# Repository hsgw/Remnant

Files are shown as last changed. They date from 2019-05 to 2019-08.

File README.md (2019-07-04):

# Remnant
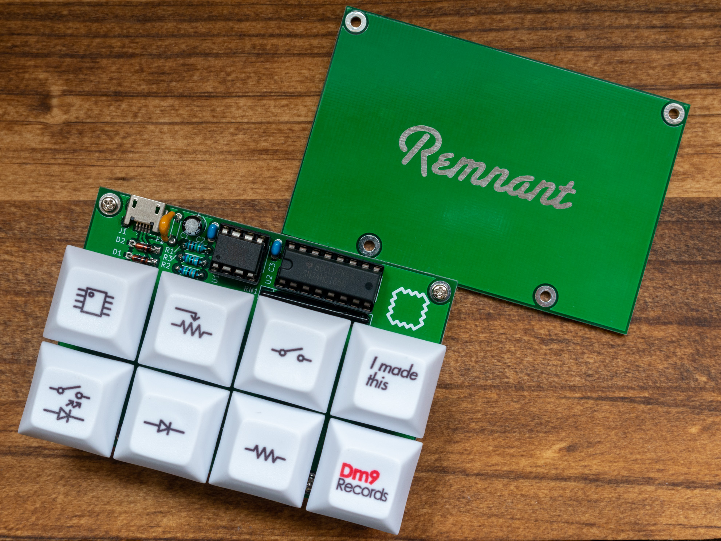
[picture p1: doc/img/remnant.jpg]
Remnant

4x2 macro keyboard with attiny85 based digispark.

# Document
- [開発環境のインストール](doc/install_env_jp.md)
- [ビルドガイド（日本語）](doc/buildguide_jp.md)

# Needs
- Arduino IDE and Digispark
https://digistump.com/wiki/digispark/tutorials/connecting

- DigisparkKeyboardExtend library 
https://github.com/hsgw/DigisparkKeyboardExtend

# License
Digispark is licensed under CC BY-SA 3.0    http://creativecommons.org/licenses/by-sa/3.0/   
(c) Digistump   

Remnant is licensed under CC BY-SA 3.0    http://creativecommons.org/licenses/by-sa/3.0/   
(c) 2019, Takuya Urakawa, dm9records.com

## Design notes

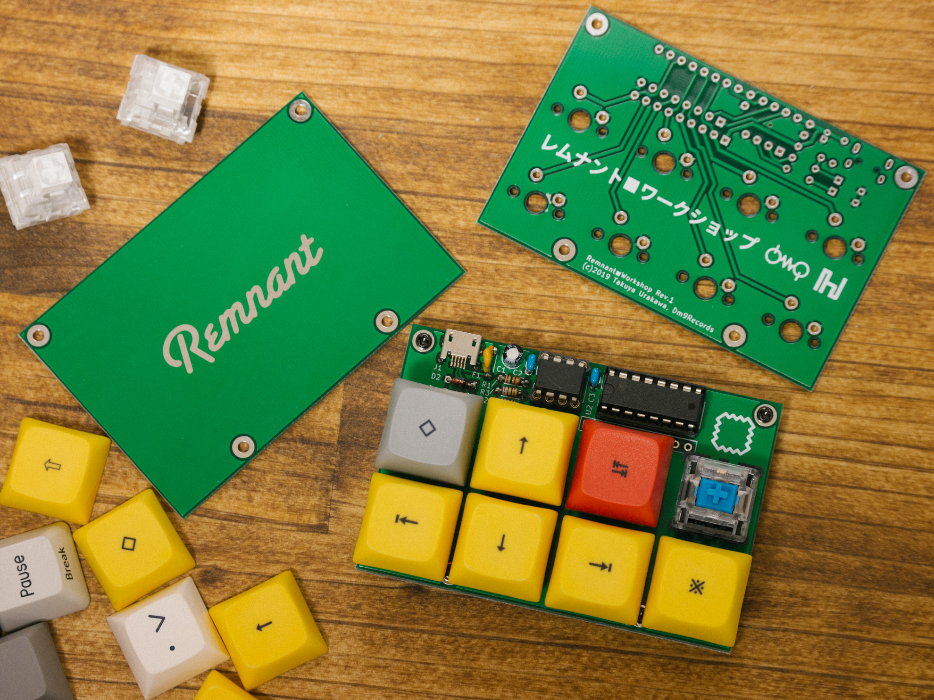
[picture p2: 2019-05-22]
remnant.jpg

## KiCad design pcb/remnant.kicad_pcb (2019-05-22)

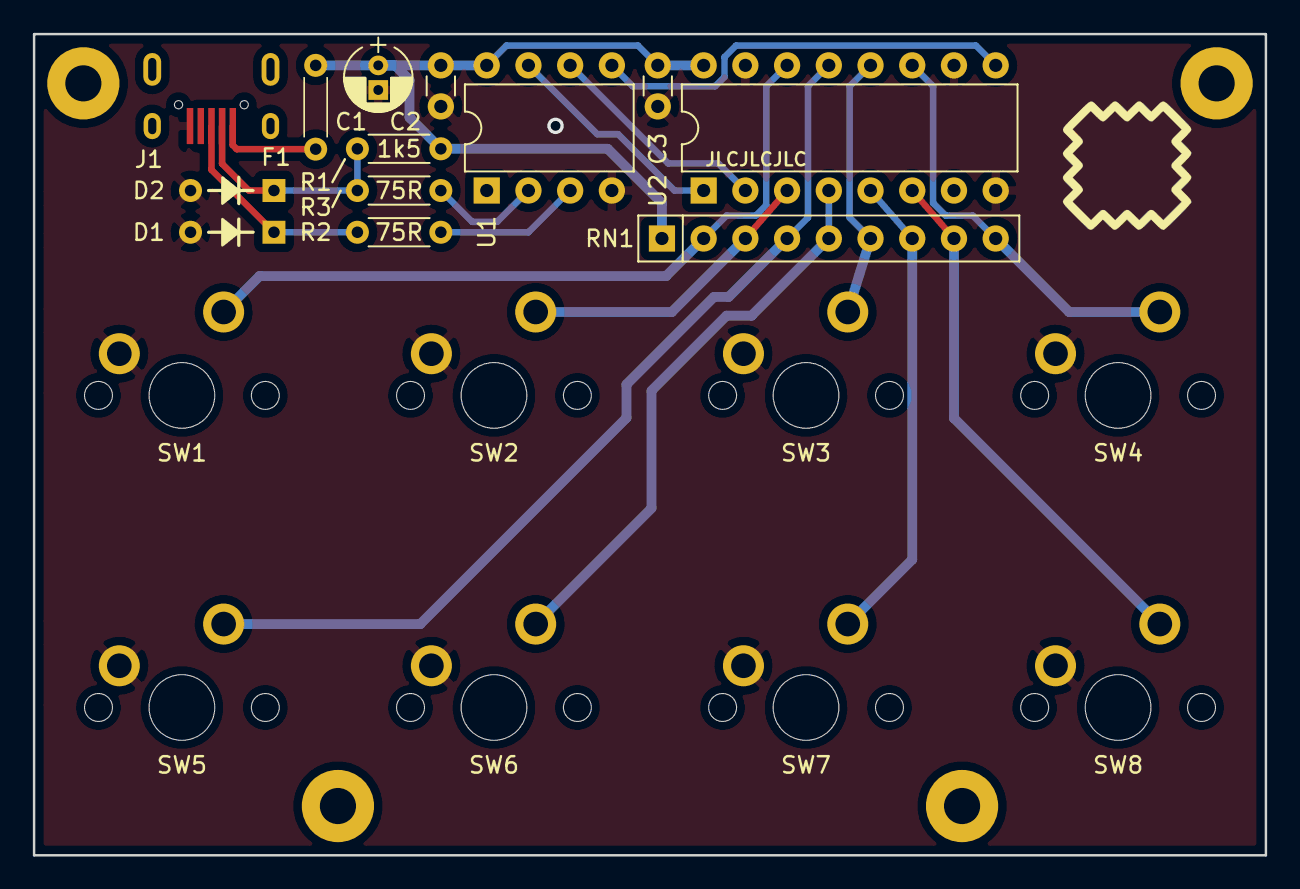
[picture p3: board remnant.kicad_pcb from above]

Board: 2 copper layers, 75.0 x 50.0 mm, 25 parts (0 on the bottom side), 18 nets.

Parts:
C1: 10u; CP_Radial_D4.0mm_P1.50mm
C2, C3: 100n; C_Disc_D3.0mm_W1.6mm_P2.50mm
D1, D2: 3.6V; D_DO-35_SOD27_P5.08mm_Horizontal
F1: 100mA; polyfuse_5.1mm
H1, H2, H3, H4: MountingHole; MountingHole_2.2mm_M2_Pad
J1: USB_OTG; USB-microB-LCSC-U-F-M5DD-W-2
R1: 1k5; R_Axial_DIN0204_L3.6mm_D1.6mm_P5.08mm_Horizontal
R2, R3: 75R; R_Axial_DIN0204_L3.6mm_D1.6mm_P5.08mm_Horizontal
RN1: R_Network08; R_Array_SIP9
SW1, SW2, SW3, SW4, SW5, SW6, SW7, SW8: MX; SW_Cherry_MX1A_1.00u_PCB
U1: ATTINY85-20PU; DIP-8_W7.62mm
U2: 74LS165; DIP-16_W7.62mm

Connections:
+5V: C1.1, C2.1, C3.1, F1.1, R1.2, RN1.1, U1.8, U2.16
/SW1: RN1.2, SW1.2, U2.14
/SW2: RN1.3, SW2.2, U2.3
/SW3: RN1.6, SW3.2, U2.12
/SW4: RN1.9, SW4.2, U2.11
/SW5: RN1.4, SW5.2, U2.13
/SW6: RN1.5, SW6.2, U2.4
/SW7: RN1.7, SW7.2, U2.5
/SW8: RN1.8, SW8.2, U2.6
/USB_D+: R2.1, U1.3
/USB_D-: R3.1, U1.2
GND: C1.2, C2.2, C3.2, D1.2, D2.2, J1.5, SW1.1, SW2.1, SW3.1, SW4.1, SW5.1, SW6.1, SW7.1, SW8.1, U1.4, U2.8, U2.10, U2.15
unnamed: D1.1, J1.3, R2.2
unnamed: D2.1, J1.2, R1.1, R3.2
unnamed: F1.2, J1.1
unnamed: U1.5, U2.9
unnamed: U1.6, U2.2
unnamed: U1.7, U2.1

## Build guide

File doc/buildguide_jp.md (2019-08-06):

# Remnant ビルドガイド

## Maker Faire Tokyo 2019にてご購入頂いた方へ
ATTINY85のbootloaderを書き忘れている物がいくつか混じっていたようです。   
誠に申し訳ありません。書き込み済みのものをお送りいたしますのでinfo@5z6p.comへご連絡頂けますでしょうか？
お手数をおかけしますが、よろしくお願いします。

- AVRへの書き込み環境のある方
以下のブートローダを書き込み、fuseを書き換えて下さい。
https://github.com/micronucleus/micronucleus

上記リポジトリをcloneしたあと、
```
cd firmwere
make CONFIG=t85_default
make CONFIG=t85_default flash
make CONFIG=t85_default fuse
```

## パーツリスト
組み立てる前にかならずパーツが全て揃っているか確認してください。

### 付属しているもの
| No | 数量 | 説明 |
|---|---|---|
| C1 | 1 | 電解コンデンサ 4.7uF |
| C2, C3 | 2 | 積層セラミックコンデンサ 0.1uF |
| D1, D2 | 2 | ショットキーダイオード 3.6V |
| F1 | 1 | ポリフューズ |
| J1 | 1 | USB microBコネクタ |
| R1 | 1 | 抵抗 1.5kΩ 茶緑黒茶茶 |
| R2, R3 | 2 | 抵抗 75Ω 紫緑黒金茶 |
| RN1 | 1 | 抵抗アレイ 10kΩx8 |
| U1 | 1 | マイコン attiny85 |
| U2 | 1 | ロジックIC 74HC165 |
| IC socket | 1 | ICソケット 16ピン |
| IC socket | 1 | ICソケット 8ピン |
| SW1-8 | 8 | MX互換スイッチ |
| キーキャップ | 8 | |
| PCB | 2 | main&bottom |
| ねじ類 | | 1セット |

### 別途必要なもの
- USB microBケーブル

## 組立

### ダイオードのはんだづけ
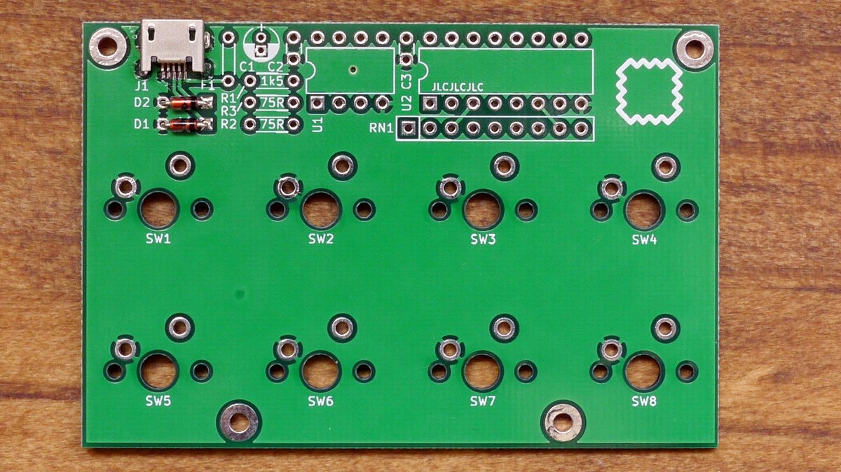
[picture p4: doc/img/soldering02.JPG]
diode


ダイオードには**実装する向き**があります。   
**部品の帯**と**基板シルクの線がある方**を合わせてください。

### 抵抗のはんだづけ
抵抗は2種類あります。間違えないように注意。

#### R1 (1.5kΩ)
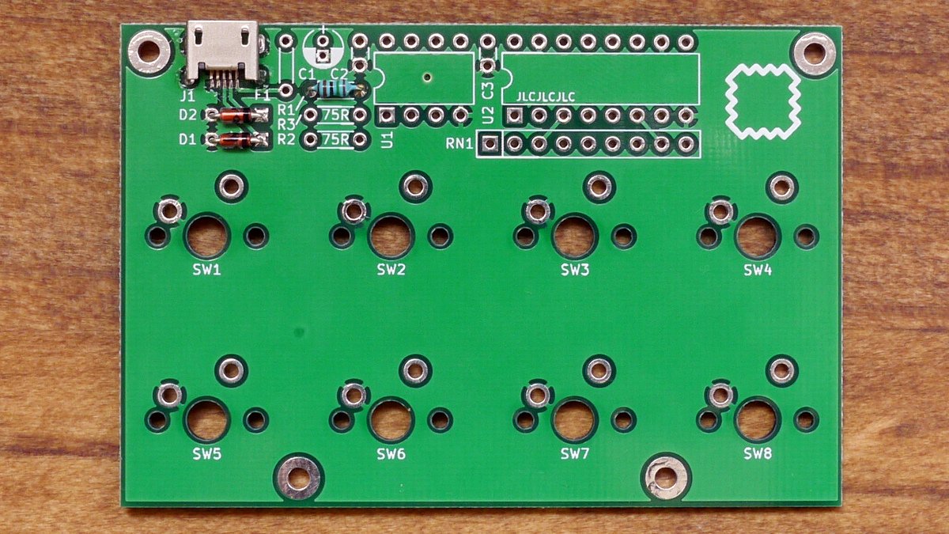
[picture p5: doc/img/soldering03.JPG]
1.5k


#### R2-3 (75Ω)
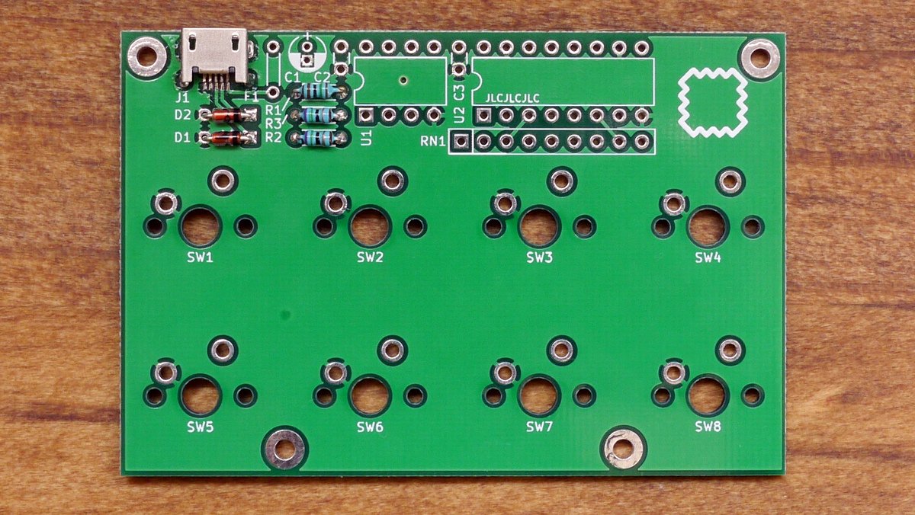
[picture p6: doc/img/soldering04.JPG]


### 積層セラミックコンデンサのはんだづけ
C2とC3をはんだづけします。
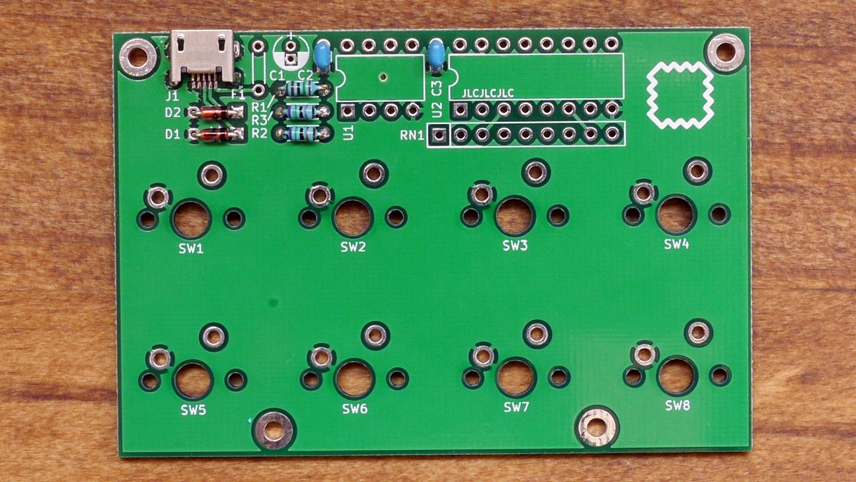
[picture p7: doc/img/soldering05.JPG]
0.1uF


### 抵抗アレイとICソケットのはんだづけ
抵抗アレイには**実装する向き**があります。   
**部品上のマーキング**と**基板シルクで囲まれたピン**を合わせてください。
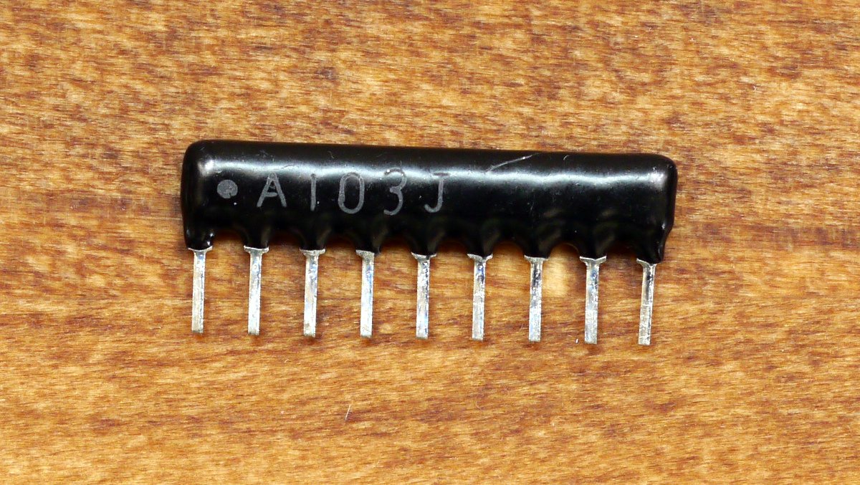
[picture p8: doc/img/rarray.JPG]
rarray


ICソケットには**実装する向き**があります。   
**部品の切りかけ**と**基板シルクの切りかけ**を合わせてください。

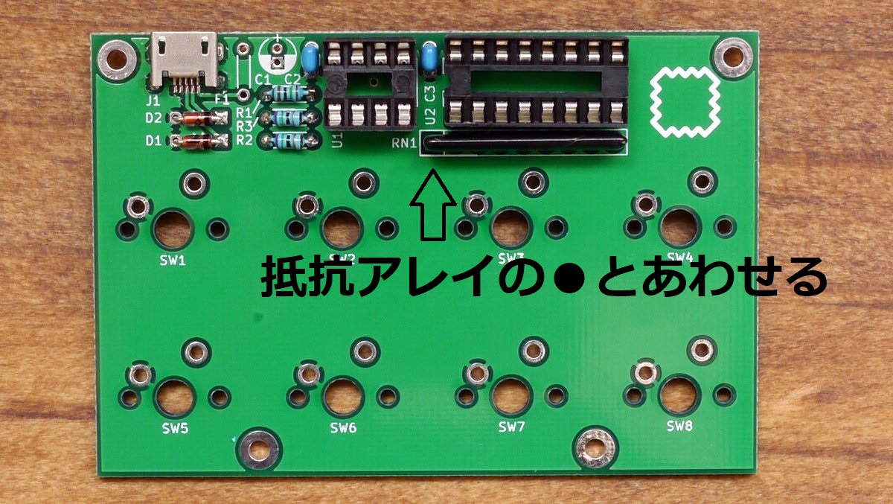
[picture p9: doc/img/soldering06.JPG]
ICソケット


### 電解コンデンサとポリフューズのはんだづけ
電解コンデンサには**実装する向き**があります。
**部品上の帯**と**基板上のシルク**を合わせてください。
電解コンデンサの足は間隔が狭いので注意してはんだづけしてください。

ポリフューズには方向はありません。

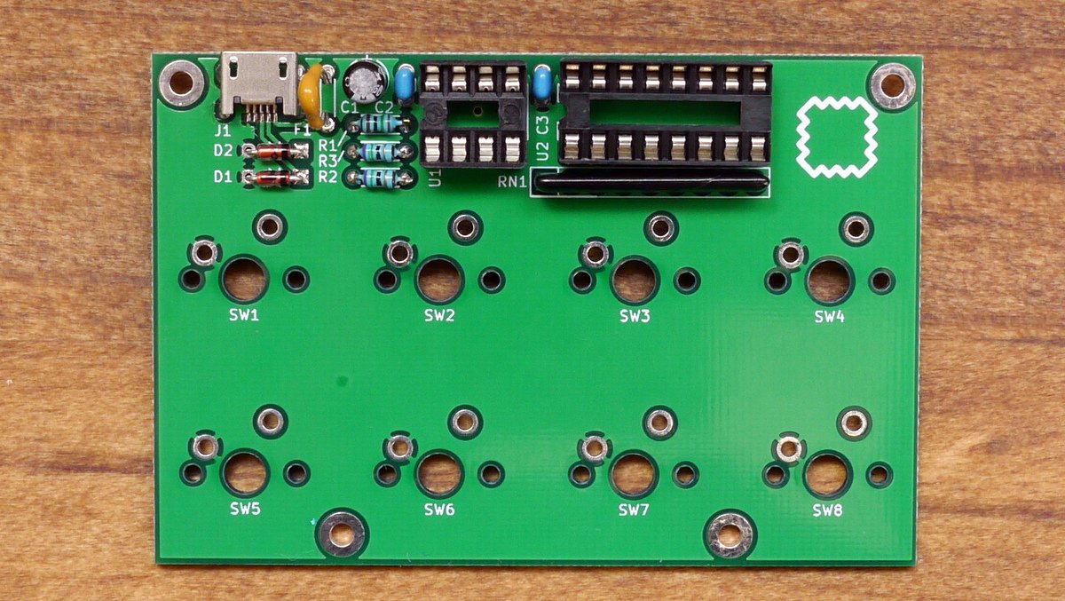
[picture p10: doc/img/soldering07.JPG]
CP&fuse


### 動作確認
はんだづけのミス、ショートなどを目視、マルチメーターで確認したあと、
USBケーブルでPCと接続してテストを行います。
ブートローダとデフォルトキーマップはプログラムされているのでキーボードとして認識されます。

#### 認識されない場合
- はんだづけを再度確認
- 部品の方向、場所が間違えていないか
- USBケーブルを変えてみる
- PCを変えてみる

### スイッチのはんだづけ
スイッチをはんだづけします。   
しっかり奥まで取り付けられているか、まっすぐかどうかを確認してからはんだ付けしてください。

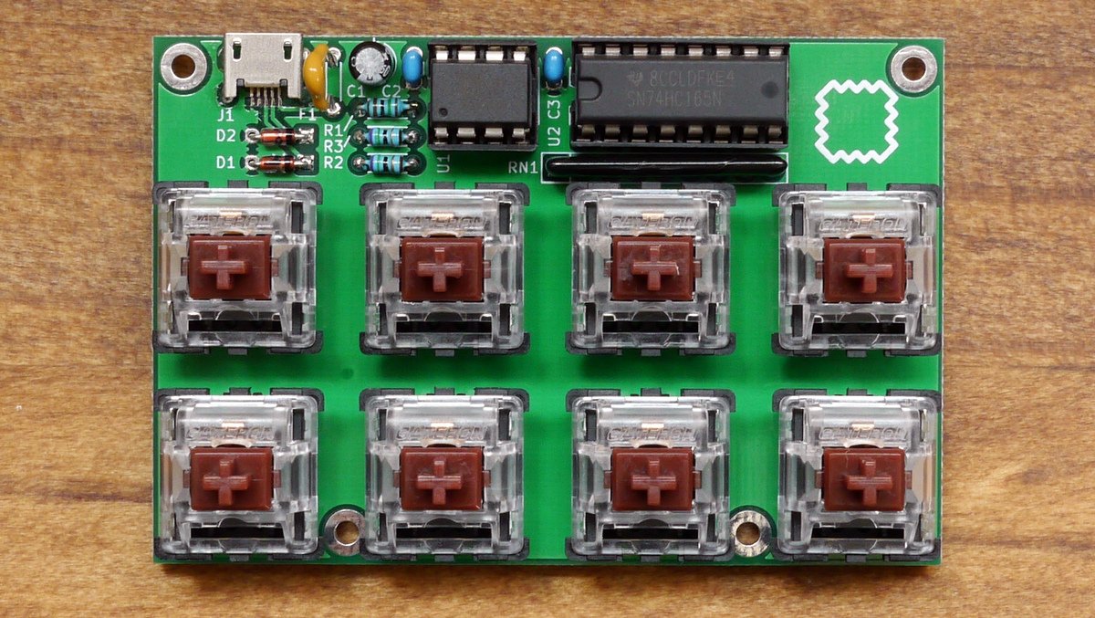
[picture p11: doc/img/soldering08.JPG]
switch


### ボトムプレートのネジ止め
上から、**ねじ**→**メイン基板**→**ナットx2**→**ボトム基板**→**ナット**の順にとりつけます。

### キーキャップをとりつけて完成

## ブートローダとファームウェアについて
### 使用する開発環境
[digispark](http://digistump.com/)互換となっているため、Arduino IDEからプログラムできます。
ブートローダに[micronucleus](https://github.com/micronucleus/micronucleus)を使用しています。

プログラムに必要なものは以下に記載していますので参考にしてください。

- [Remnantの開発環境](install_env_jp.md)

### ファームウェアについて
このリポジトリの[src](../src)内にあります。   

### キーマップのカスタマイズについて

以下の部分を書き換えることでキーマップのカスタマイズが行えます。
使えるキーコードについては[こちら](https://github.com/hsgw/DigisparkKeyboardExtend/blob/master/src/keycode.h)にあります。

```
const uint16_t PROGMEM keymap[SWITCHES_NUM] = 
  LAYOUT( 
    LCTL(KC_A), LCTRL(KC_C), KC_UP,       LCTRL(KC_V),
    KC_LSFT,    KC_LEFT,     KC_DOWN,     KC_RIGHT
  );
```

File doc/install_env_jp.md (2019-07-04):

# Remnantの開発環境
## 必要なもの
- Arduino IDE
- Digispark開発環境
- DigisparkKeyboardExtendライブラリ

## Arduino IDEのインストール
https://www.arduino.cc/en/Main/Software　からダウンロードして最新版をインストールする

## Digispark開発環境のインストール
インストールしたArduino IDEにDigisparkの開発環境を追加する

(参考)
- http://digistump.com/wiki/digispark/tutorials/connecting
- https://qiita.com/mt08/items/df4ed8c659b205d1fa1e

# DigisparkKeyboardExtendライブラリを追加する
https://github.com/hsgw/DigisparkKeyboardExtend からダウンロード/cloneしてインストールする

// Arduino IDEからのライブラリインストールには対応していません

(参考)
- http://www.humblesoft.com/wiki/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

# remnant.inoをコンパイルする
このリポジトリの[src/remnant/remnant.ino](../src/remnant/remnant.ino)を開いてコンパイルする

```ツール```→```ボード```から```Digispark (Default - 16.5mhz) ```を選択すること！

# 書き込み時の注意点
- コンパイル後にファームウェアを書き込む場合はUSBケーブルを抜き差しする必要があります

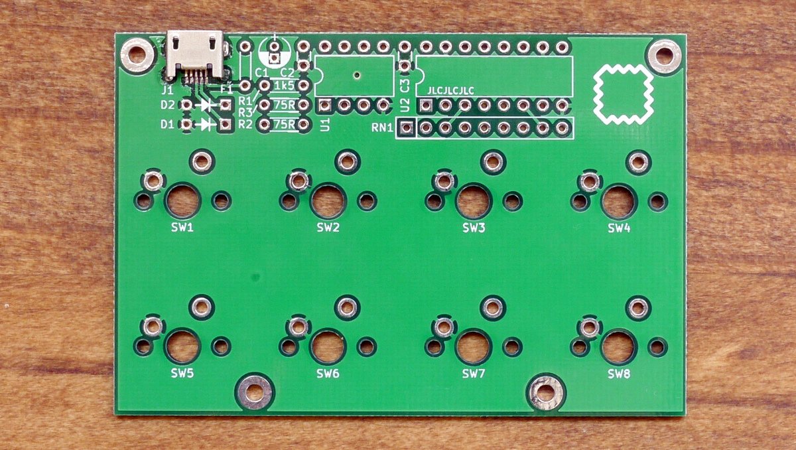
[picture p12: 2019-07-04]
doc/img/soldering01.JPG

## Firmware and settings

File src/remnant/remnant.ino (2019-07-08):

#include "remnant.h"

const uint16_t PROGMEM keymap[SWITCHES_NUM] = 
  LAYOUT( 
    LCTL(KC_A), LCTL(KC_C),  KC_UP,       LCTL(KC_V),
    KC_LSFT,    KC_LEFT,     KC_DOWN,     KC_RIGHT
  );

Remnant remnant;

void setup() {
  // put your setup code here, to run once:

}

void loop() {
  // put your main code here, to run repeatedly:
  remnant.update();
}

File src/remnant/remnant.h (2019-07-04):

// If use JIS keymap and sendString(), uncomment below.
// #define USE_JIS

#include <DigiKeyboardExt.h>
#include <keycode.h>

#define _delay_165() _delay_us(5)

#define LAYOUT(k1,k2,k3,k4,k5,k6,k7,k8) {k8,k7,k6,k2,k1,k5,k3,k4}
#define SWITCHES_NUM (8)

extern const uint16_t PROGMEM keymap[SWITCHES_NUM];

enum KeyEvent {
  NoEvent = 0,
  Pushed,
  Holding,
  Released
};

__attribute__((weak)) bool process_keycode(uint16_t keyCode, KeyEvent keyEvent) {
  return true;
}

class Remnant {
  enum {
    PIN_165_DATA = 0,
    PIN_165_CLK = 1,
    PIN_165_LOAD = 2
  };
  
  public:
    Remnant () {
      validSwState = 0;
      prevSwState = 0;
      // set pin output
      DDRB |= (_BV(PIN_165_LOAD) | _BV(PIN_165_CLK));
      // set pin initial state
      PORTB |= _BV(PIN_165_LOAD);
    }
    
    void update() {
      // LOAD pulse
      PORTB &= ~_BV(PIN_165_LOAD);
      _delay_165();
      PORTB |= _BV(PIN_165_LOAD);
      _delay_165();

      uint8_t currentSwState = 0;
      for (uint8_t i=0;i<SWITCHES_NUM;i++) {
        // read switches
        currentSwState |= bit_is_clear(PINB,PIN_165_DATA)? 1 << i:0;
        // clock pulse
        PORTB |= _BV(PIN_165_CLK);
        _delay_165();
        PORTB &= ~_BV(PIN_165_CLK);
      } 

      if(currentSwState == prevSwState) {
        for(uint8_t i=0; i<SWITCHES_NUM; i++) {
          uint8_t current = bit_is_set(currentSwState, i);
          uint8_t prev = bit_is_set(validSwState, i);
          
          if (!prev && current) {
            keyEvents[i] = Pushed;
          }else if(prev && current){
            keyEvents[i] = Holding;
          }else if(prev && !current){
            keyEvents[i] = Released;
          }else{
            keyEvents[i] = NoEvent;
          }
        }
        
        validSwState = currentSwState;

        kbd.initKeyCode();

        for(uint8_t i=0; i<SWITCHES_NUM; i++) {
          if(keyEvents[i] != NoEvent) {
            uint16_t keyCode = pgm_read_word_near(keymap + i);
            if(process_keycode(keyCode, keyEvents[i])) {
              if((keyCode & 0xFF) < (SAFE_RANGE & (0xFF - 1))) {
                if(keyEvents[i] == Pushed || keyEvents[i] == Holding) {
                  kbd.registerKeyCode(keyCode);
                }
              }
            }
          }
        }

        kbd.sendRegisteredKeyCode();
        
      } else {
        // bounce
        prevSwState = currentSwState;
        kbd.delay(1);
      }
    }
  
  private:
    uint8_t validSwState;
    uint8_t prevSwState;

    KeyEvent keyEvents[8] = {NoEvent}; 
};

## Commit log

2019-05-22 1st commit
    [remnant.kicad_pcb, remnant.sch, remnant_bottom.kicad_pcb]
2019-05-22 add arduino src
